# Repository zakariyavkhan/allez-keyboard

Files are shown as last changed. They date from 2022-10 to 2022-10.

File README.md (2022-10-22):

allez

An STM32F103 based 40% mechanical keyboard. PCB and switch plate designed in KiCAD.

- Custom firmware supported through QMK
    - [allez](https://github.com/zakariyavkhan/qmk_firmware/tree/master/keyboards/allez)
    - [allez-hw](https://github.com/zakariyavkhan/qmk_firmware/tree/master/keyboards/allez_hw)

PCBs and switch plates can be ordered through JLCPCB, who will also do PCBA for a very reasonable price. BOM will have to be generated via LCSC.

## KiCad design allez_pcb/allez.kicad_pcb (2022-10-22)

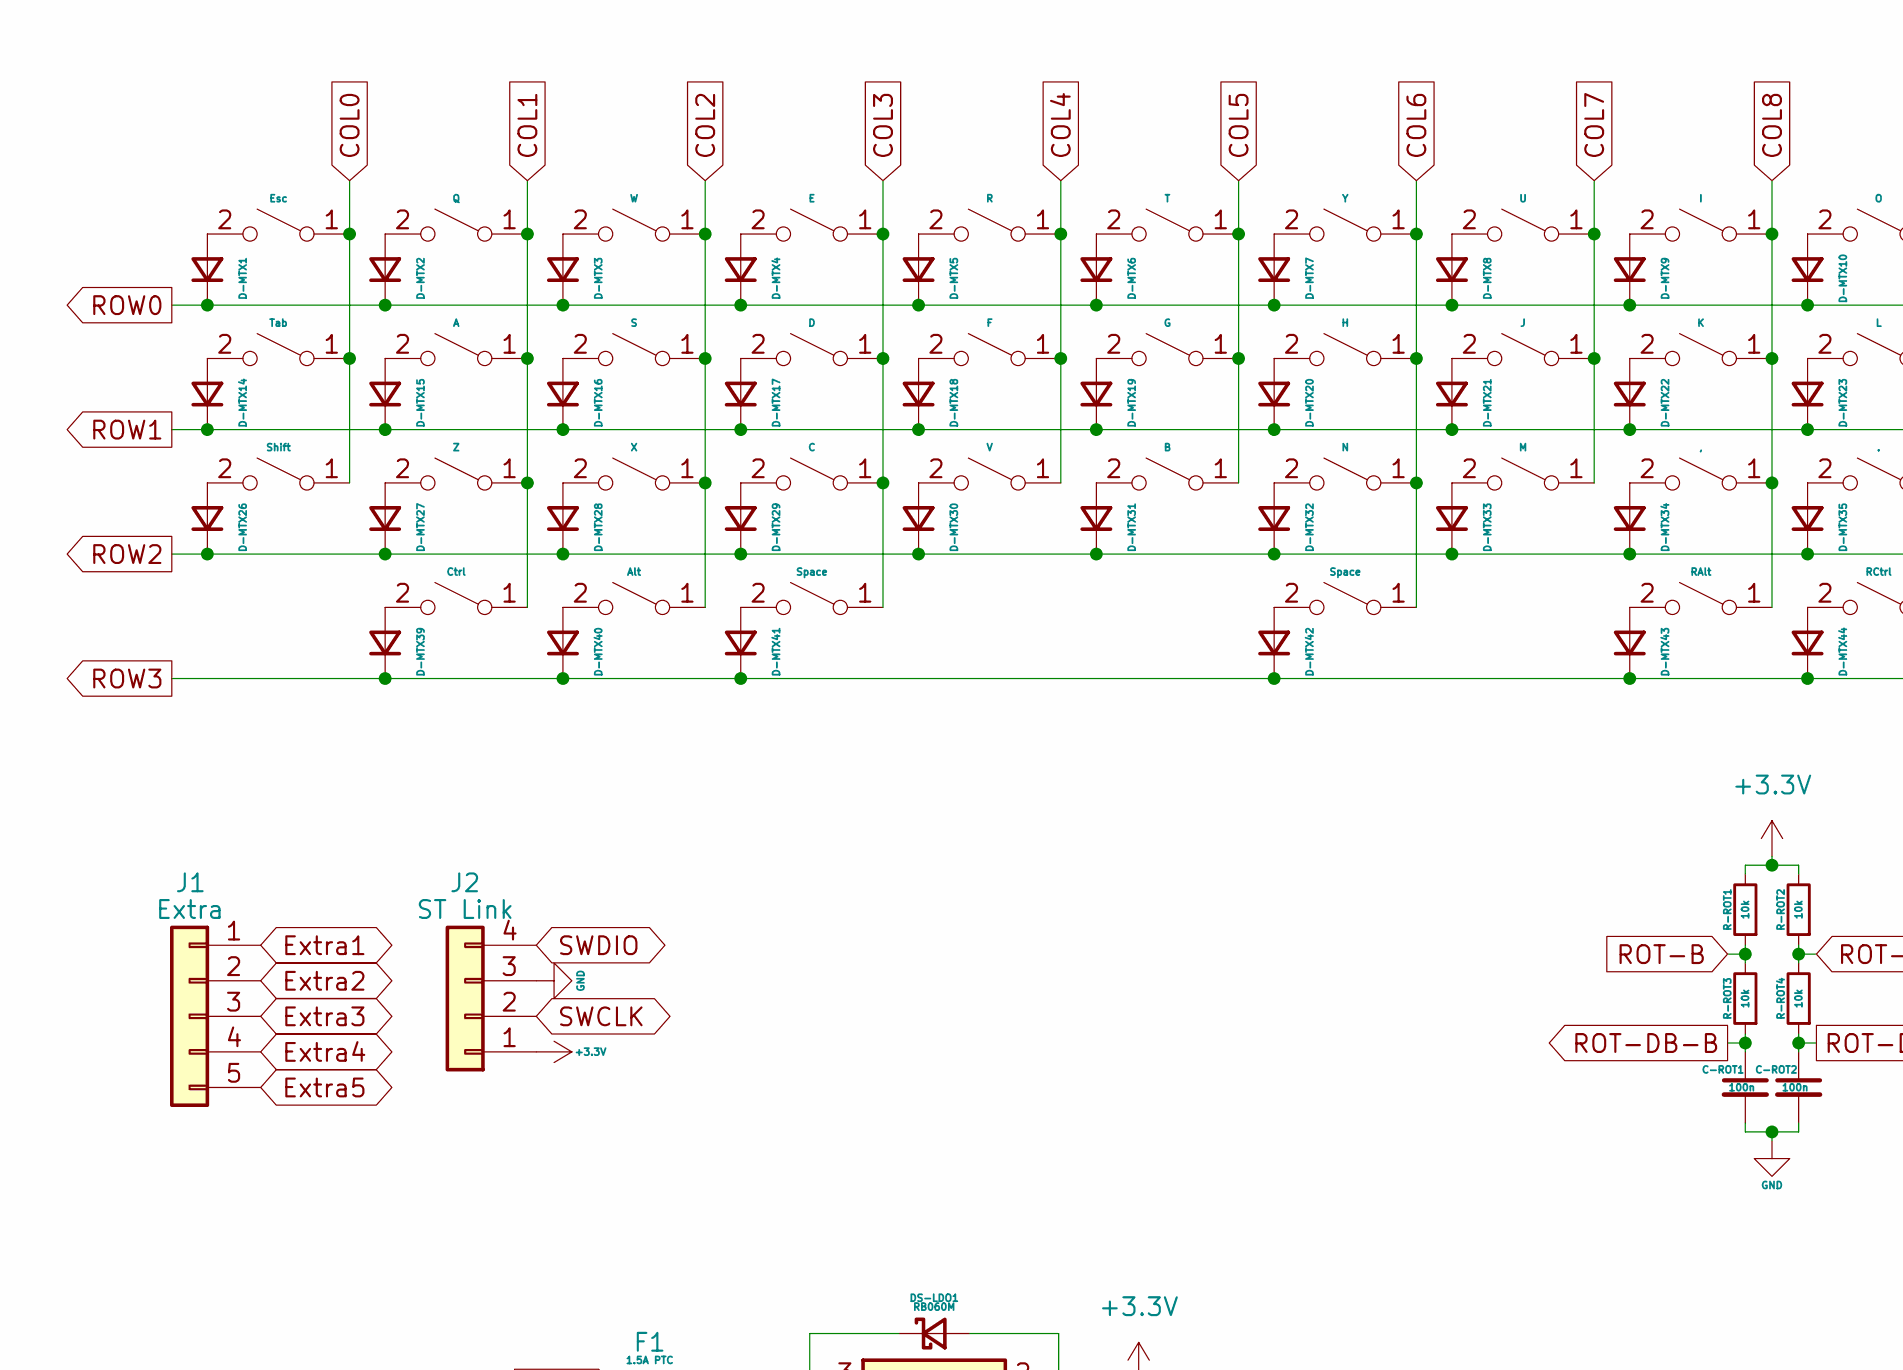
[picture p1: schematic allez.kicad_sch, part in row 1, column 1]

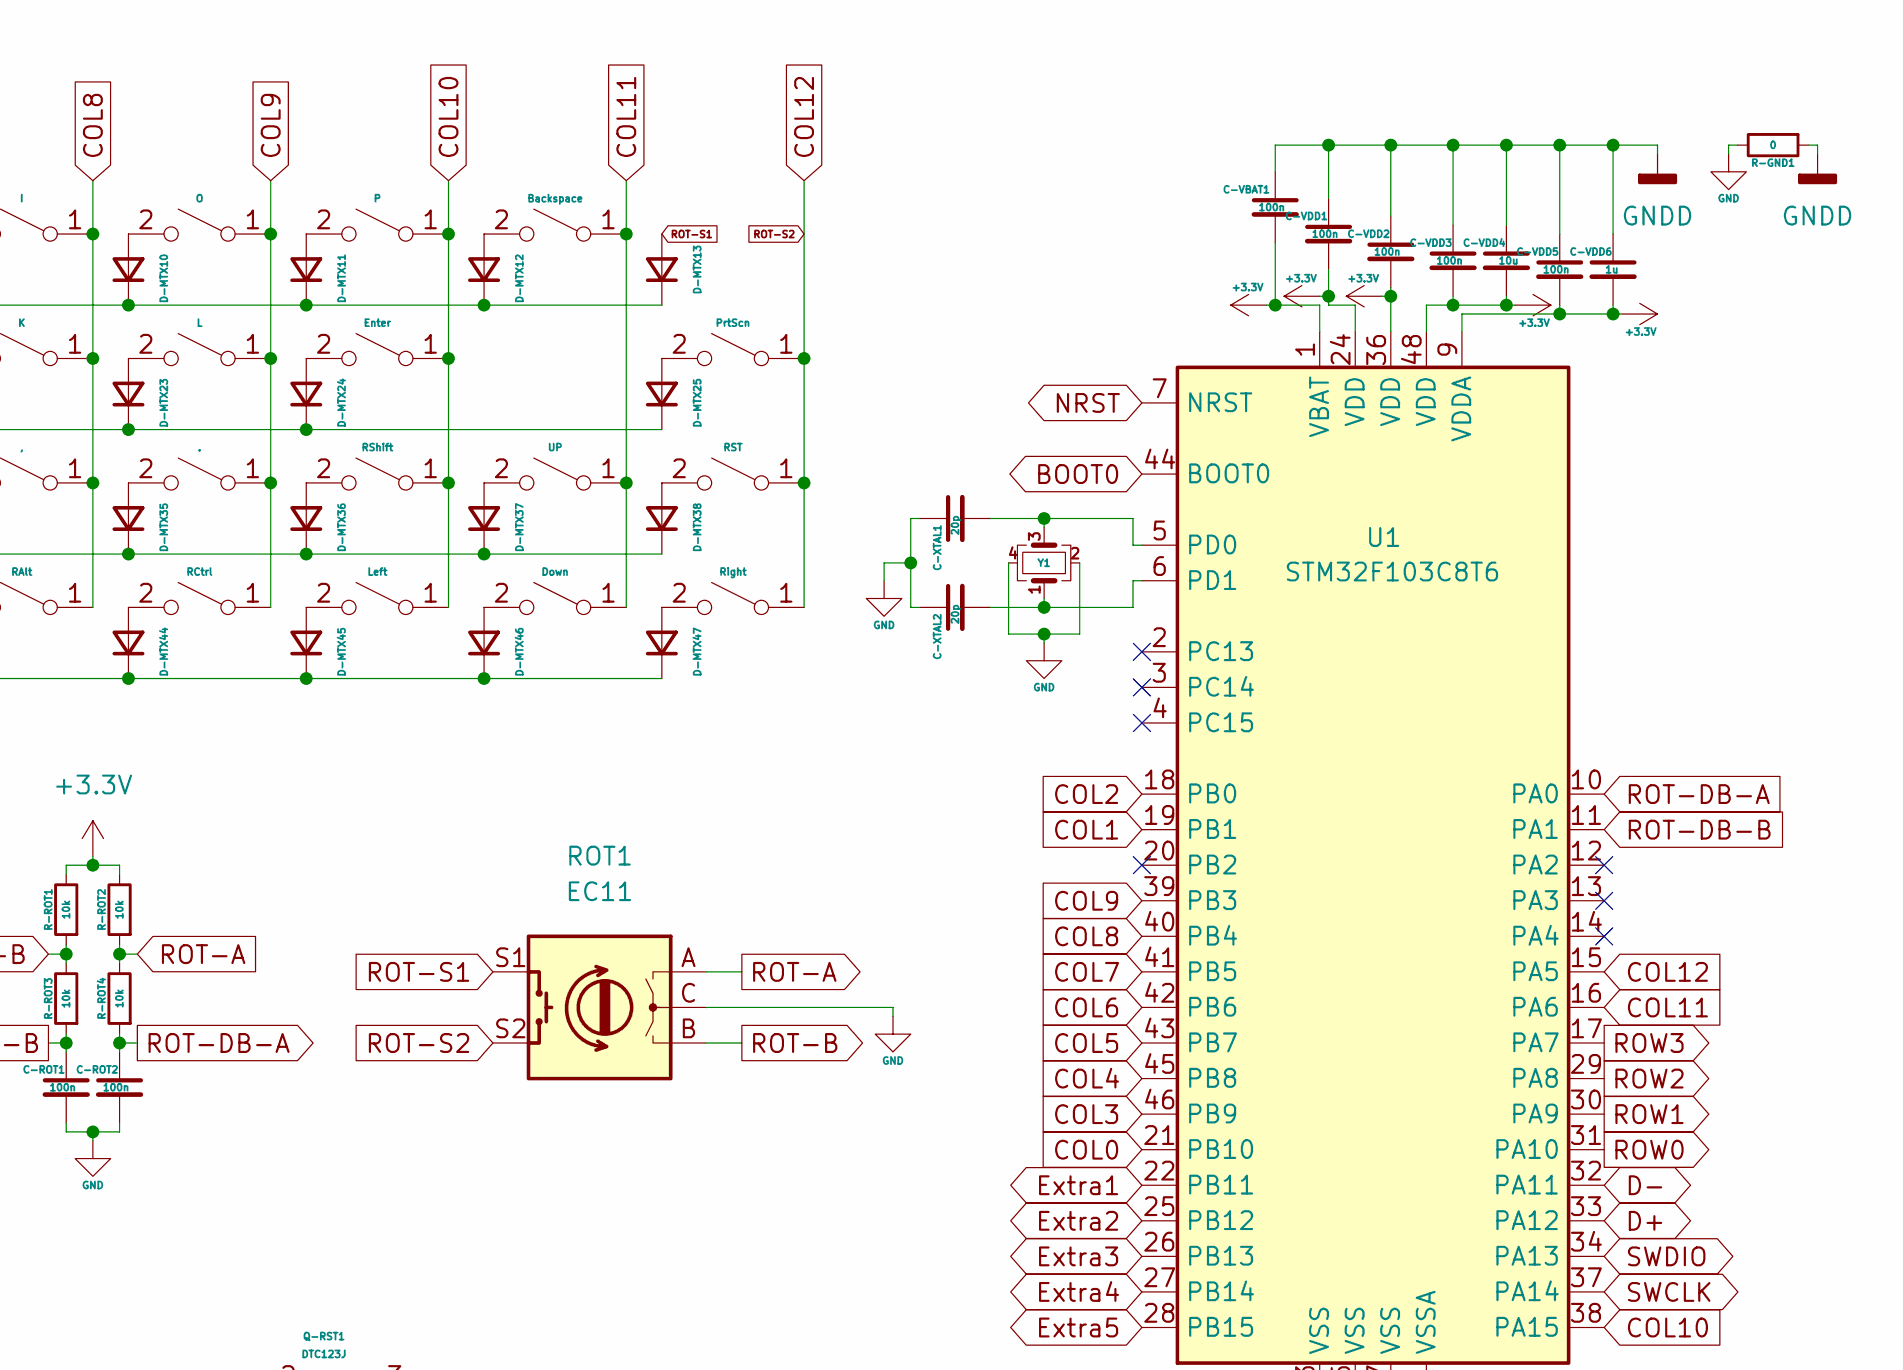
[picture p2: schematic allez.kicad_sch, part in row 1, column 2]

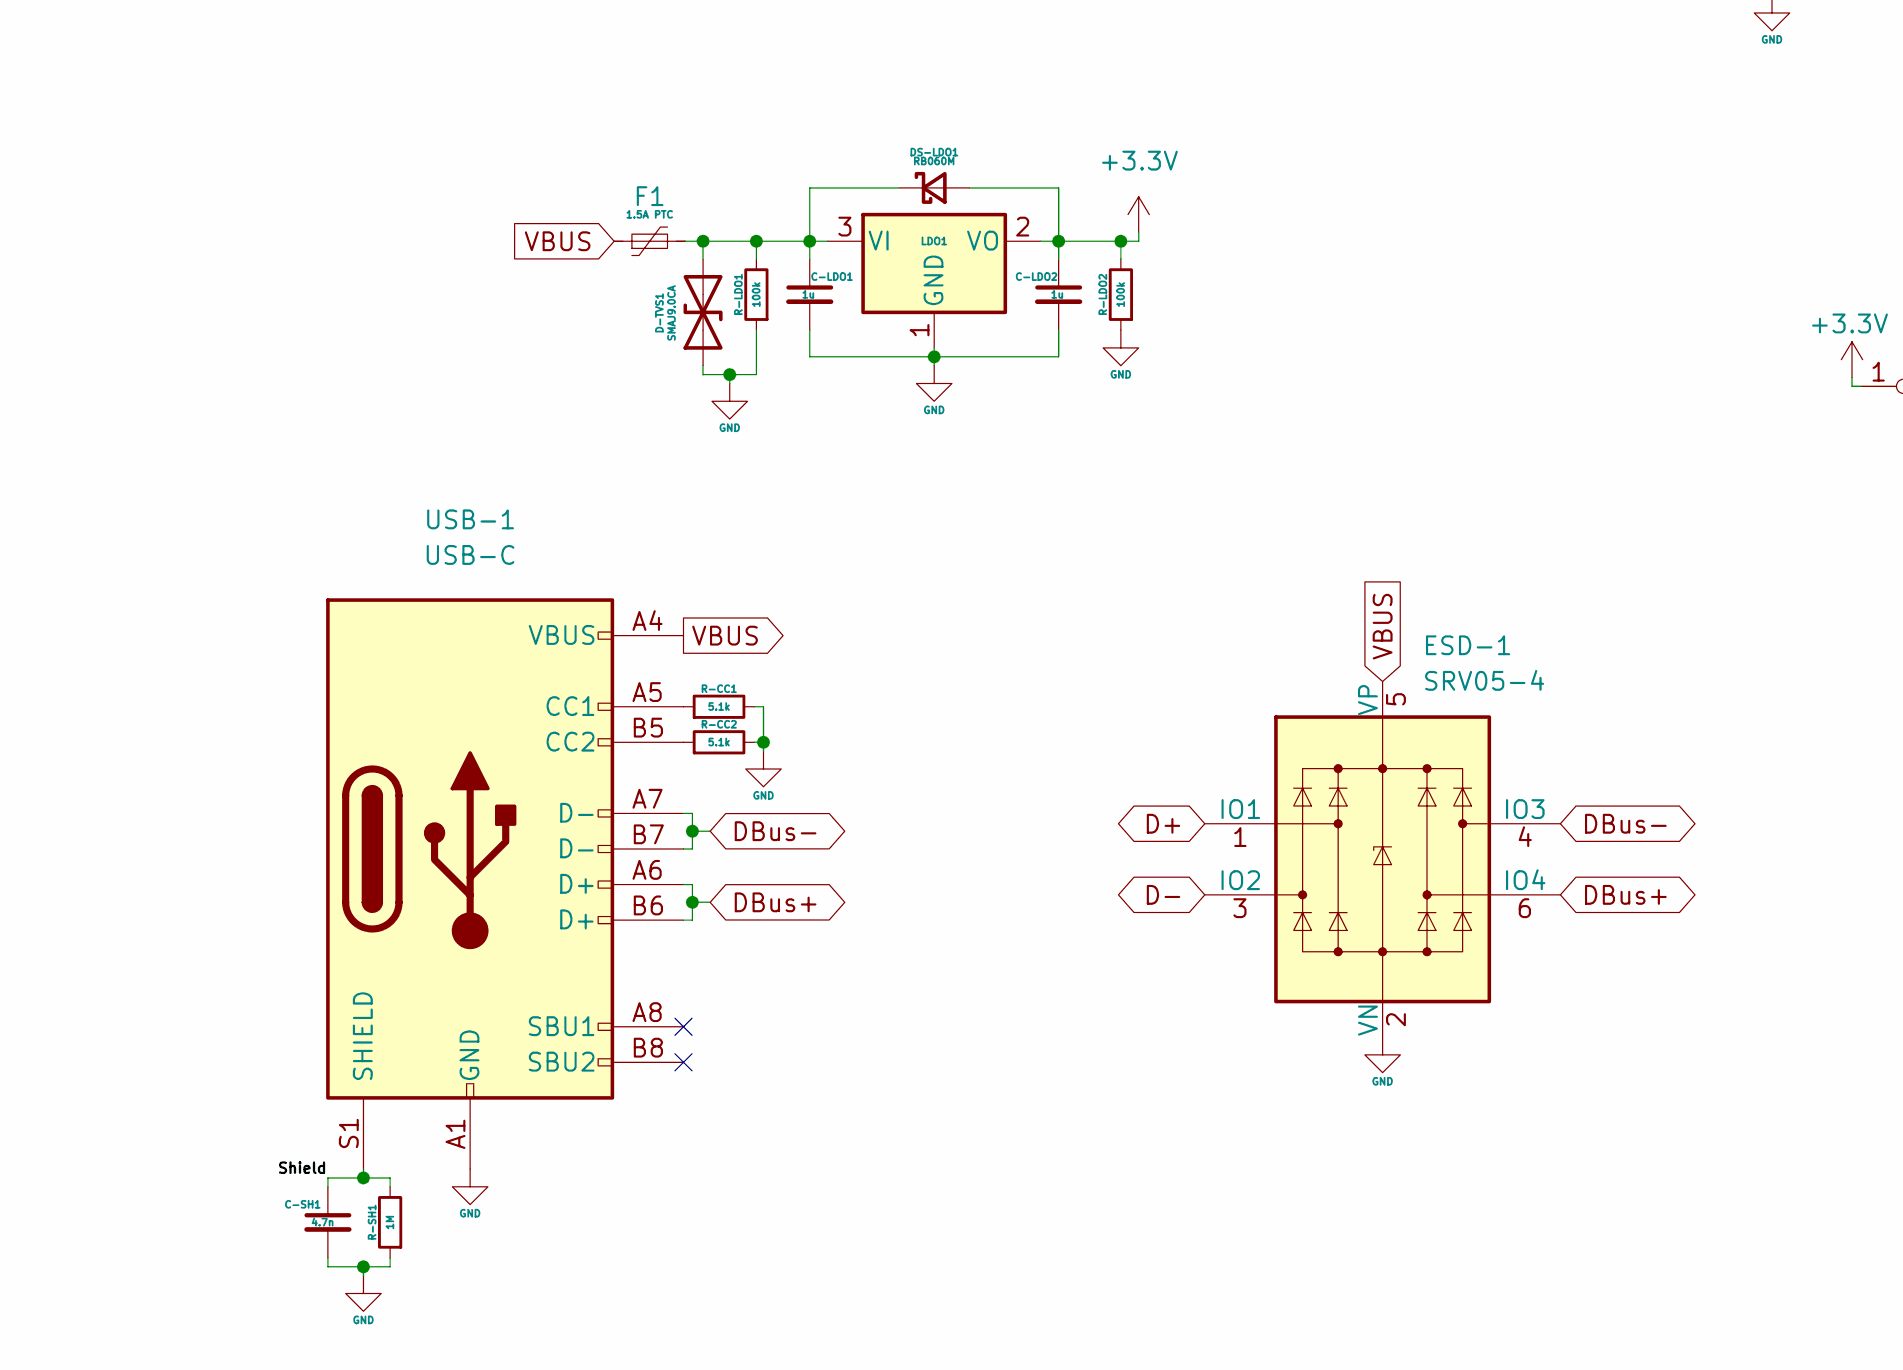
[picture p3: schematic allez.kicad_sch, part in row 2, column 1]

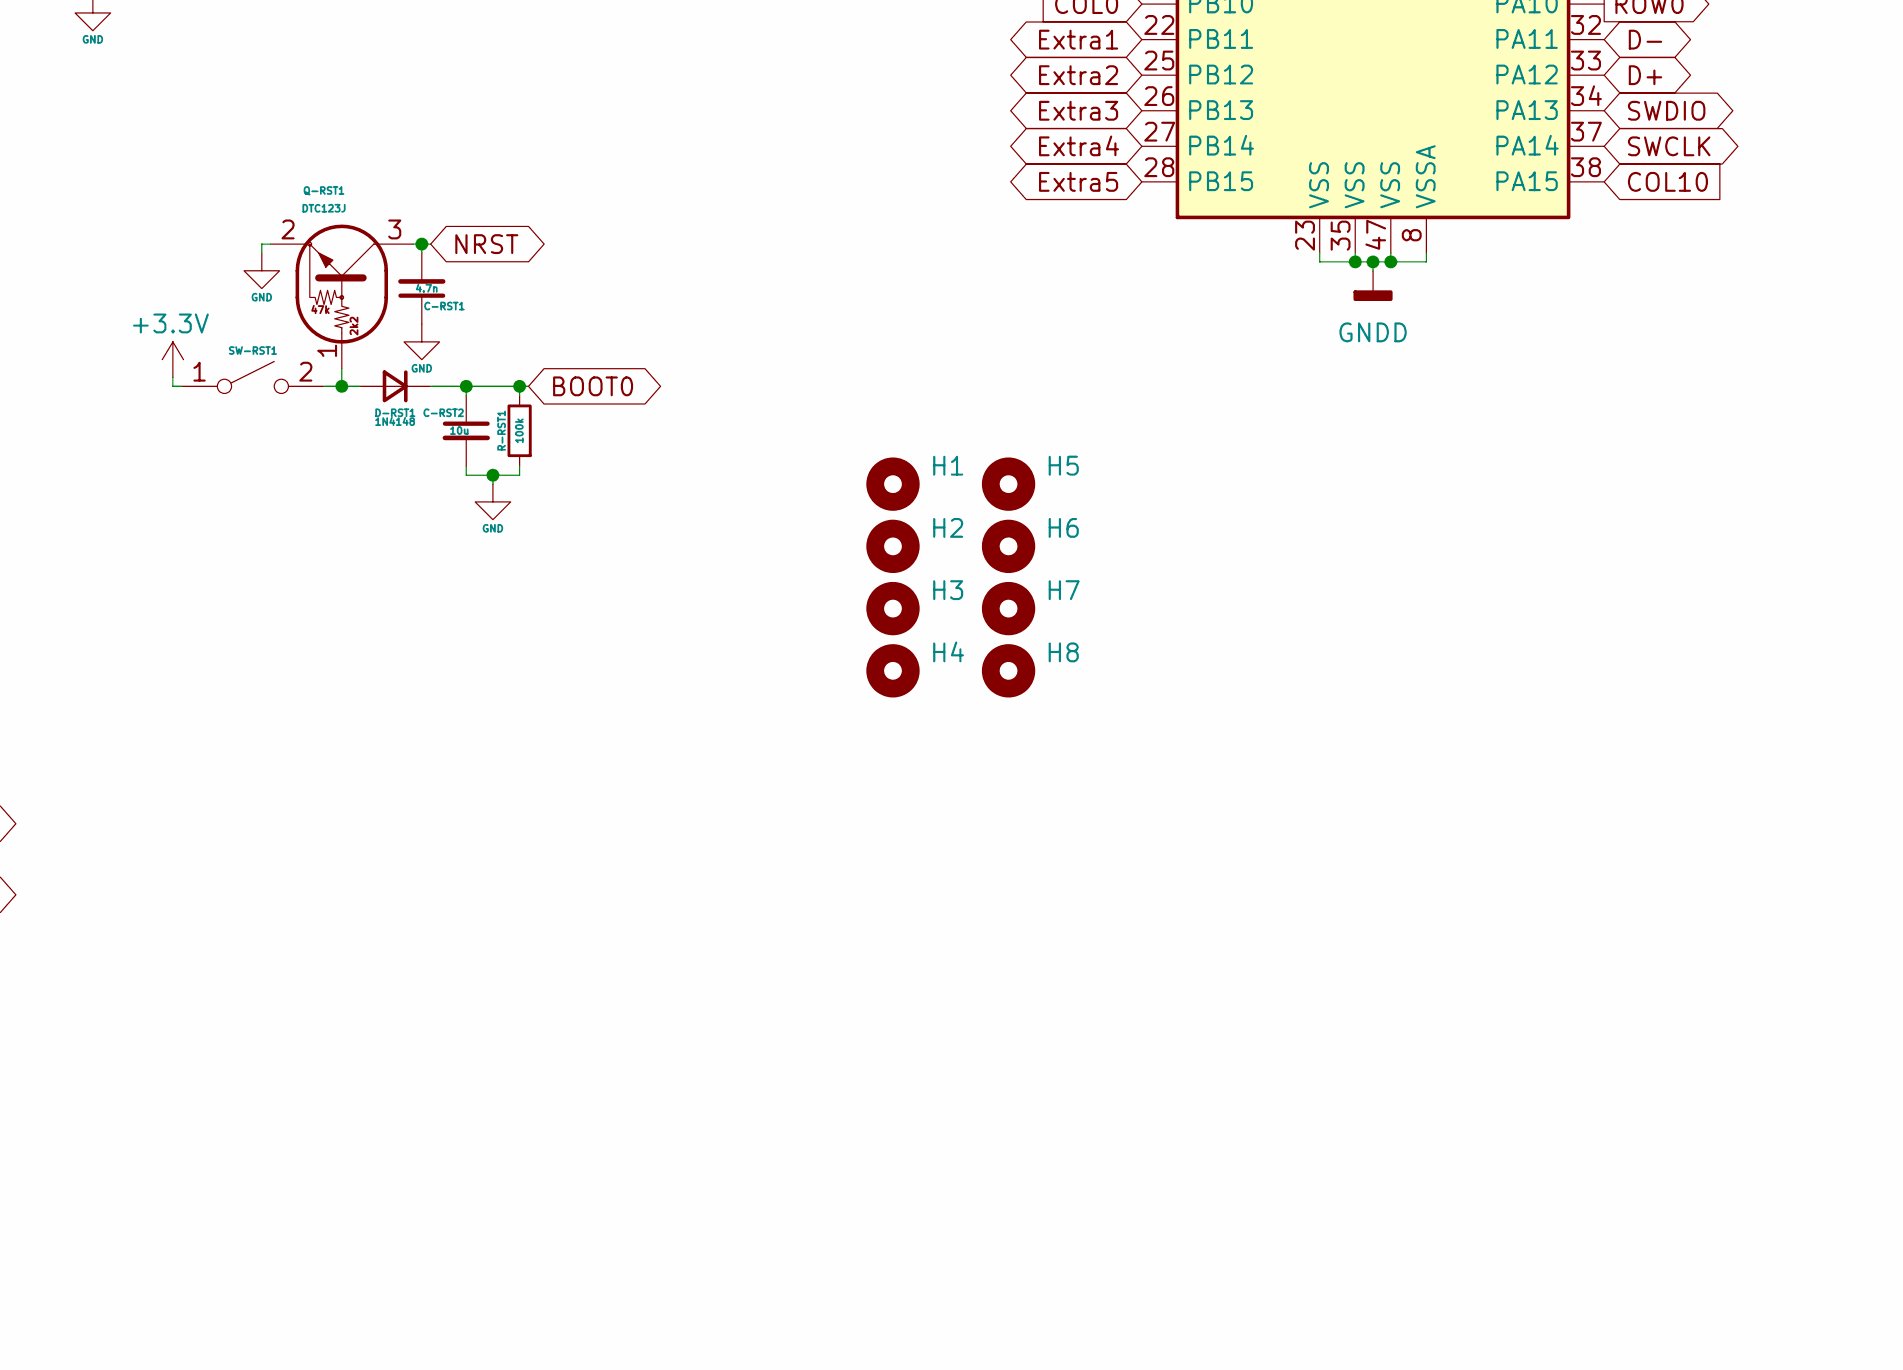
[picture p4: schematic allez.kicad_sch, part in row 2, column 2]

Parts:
C-LDO1, C-LDO2: 1u; C_0603_1608Metric_Pad1.08x0.95mm_HandSolder
C-ROT1, C-ROT2: 100n; C_0603_1608Metric_Pad1.08x0.95mm_HandSolder
C-RST1: 4.7n; C_0603_1608Metric_Pad1.08x0.95mm_HandSolder
C-RST2: 10u; C_0603_1608Metric_Pad1.08x0.95mm_HandSolder
C-SH1: 4.7n; C_0603_1608Metric_Pad1.08x0.95mm_HandSolder
C-VBAT1: 100n; C_0603_1608Metric_Pad1.08x0.95mm_HandSolder
C-VDD1, C-VDD2, C-VDD3, C-VDD5: 100n; C_0603_1608Metric_Pad1.08x0.95mm_HandSolder
C-VDD4: 10u; C_0603_1608Metric_Pad1.08x0.95mm_HandSolder
C-VDD6: 1u; C_0603_1608Metric_Pad1.08x0.95mm_HandSolder
C-XTAL1, C-XTAL2: 20p; C_0603_1608Metric_Pad1.08x0.95mm_HandSolder
D-MTX1, D-MTX2, D-MTX3, D-MTX4, D-MTX5, D-MTX6, D-MTX7, D-MTX8, D-MTX9, D-MTX10, D-MTX11, D-MTX12, D-MTX13, D-MTX14, D-MTX15, D-MTX16, D-MTX17, D-MTX18, D-MTX19, D-MTX20, D-MTX21, D-MTX22, D-MTX23, D-MTX24, D-MTX25, D-MTX26, D-MTX27, D-MTX28, D-MTX29, D-MTX30, D-MTX31, D-MTX32, D-MTX33, D-MTX34, D-MTX35, D-MTX36, D-MTX37, D-MTX38, D-MTX39, D-MTX40, D-MTX41, D-MTX42, D-MTX43, D-MTX44, D-MTX45, D-MTX46, D-MTX47: 1N4148; D_0603_1608Metric_Pad1.05x0.95mm_HandSolder
D-RST1: 1N4148; D_0603_1608Metric_Pad1.05x0.95mm_HandSolder
D-TVS1: SMAJ9.0CA; D_SMA
DS-LDO1: RB060M; D_SOD-123F
ESD-1: SRV05-4; SOT-23-6
F1: 1.5A PTC; Fuse_1812_4532Metric_Pad1.30x3.40mm_HandSolder
H1, H2, H3, H4, H5, H6, H7, H8: MountingHole; MountingHole_3.2mm_M3
J1: Extra; PinHeader_1x05_P2.54mm_Vertical
J2: ST Link; PinHeader_1x04_P2.54mm_Vertical
LDO1: XC6206; SOT-23
MX1: Esc; SW_Cherry_MX_1.00u_PCB
MX2: Q; SW_Cherry_MX_1.00u_PCB
MX3: W; SW_Cherry_MX_1.00u_PCB
MX4: E; SW_Cherry_MX_1.00u_PCB
MX5: R; SW_Cherry_MX_1.00u_PCB
MX6: T; SW_Cherry_MX_1.00u_PCB
MX7: Y; SW_Cherry_MX_1.00u_PCB
MX8: U; SW_Cherry_MX_1.00u_PCB
MX9: I; SW_Cherry_MX_1.00u_PCB
MX10: O; SW_Cherry_MX_1.00u_PCB
MX11: P; SW_Cherry_MX_1.00u_PCB
MX12: Backspace; SW_Cherry_MX_1.00u_PCB
MX14: Tab; SW_Cherry_MX_1.25u_PCB
MX15: A; SW_Cherry_MX_1.00u_PCB
MX16: S; SW_Cherry_MX_1.00u_PCB
MX17: D; SW_Cherry_MX_1.00u_PCB
MX18: F; SW_Cherry_MX_1.00u_PCB
MX19: G; SW_Cherry_MX_1.00u_PCB
MX20: H; SW_Cherry_MX_1.00u_PCB
MX21: J; SW_Cherry_MX_1.00u_PCB
MX22: K; SW_Cherry_MX_1.00u_PCB
MX23: L; SW_Cherry_MX_1.00u_PCB
MX24: Enter; SW_Cherry_MX_1.75u_PCB
MX25: PrtScn; SW_Cherry_MX_1.00u_PCB
MX26: Shift; SW_Cherry_MX_1.50u_PCB
MX27: Z; SW_Cherry_MX_1.00u_PCB
MX28: X; SW_Cherry_MX_1.00u_PCB
MX29: C; SW_Cherry_MX_1.00u_PCB
MX30: V; SW_Cherry_MX_1.00u_PCB
MX31: B; SW_Cherry_MX_1.00u_PCB
MX32: N; SW_Cherry_MX_1.00u_PCB
MX33: M; SW_Cherry_MX_1.00u_PCB
MX34: ,; SW_Cherry_MX_1.00u_PCB
MX35: .; SW_Cherry_MX_1.00u_PCB
MX36: RShift; SW_Cherry_MX_1.25u_PCB
MX37: UP; SW_Cherry_MX_1.00u_PCB
MX38: RST; SW_Cherry_MX_1.00u_PCB
MX39: Ctrl; SW_Cherry_MX_1.25u_PCB
MX40: Alt; SW_Cherry_MX_1.00u_PCB
MX41: Space; SW_Cherry_MX_2.25u_PCB
MX42: Space; SW_Cherry_MX_2.75u_PCB
MX43: RAlt; SW_Cherry_MX_1.00u_PCB
MX44: RCtrl; SW_Cherry_MX_1.25u_PCB
MX45: Left; SW_Cherry_MX_1.00u_PCB
MX46: Down; SW_Cherry_MX_1.00u_PCB
MX47: Right; SW_Cherry_MX_1.00u_PCB
Q-RST1: DTC123J; SOT-23
R-CC1, R-CC2: 5.1k; R_0603_1608Metric_Pad0.98x0.95mm_HandSolder
R-GND1: 0; R_0603_1608Metric_Pad0.98x0.95mm_HandSolder
R-LDO1, R-LDO2: 100k; R_0603_1608Metric_Pad0.98x0.95mm_HandSolder
R-ROT1, R-ROT2, R-ROT3, R-ROT4: 10k; R_0603_1608Metric_Pad0.98x0.95mm_HandSolder
R-RST1: 100k; R_0603_1608Metric_Pad0.98x0.95mm_HandSolder
R-SH1: 1M; R_0603_1608Metric_Pad0.98x0.95mm_HandSolder
ROT1: EC11; RotaryEncoder_Alps_EC11E-Switch_Vertical_H20mm
SW-RST1: SPST; SW_SPST_TL3342
U1: STM32F103C8T6; LQFP-48_7x7mm_P0.5mm
USB-1: USB-C; USB_C_Receptacle_HRO_TYPE-C-31-M-12
Y1: 8MHz; Crystal_SMD_3225-4Pin_3.2x2.5mm_HandSoldering

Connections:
+3.3V: C-LDO2.1, C-VBAT1.2, C-VDD1.2, C-VDD2.2, C-VDD3.2, C-VDD4.2, C-VDD5.2, C-VDD6.2, DS-LDO1.2 (A), J2.1, LDO1.2 (VO), R-LDO2.2, R-ROT1.2, R-ROT2.2, SW-RST1.1 (A), U1.1 (VBAT), U1.9 (VDDA), U1.24 (VDD), U1.36 (VDD), U1.48 (VDD)
/Shield: C-SH1.1, R-SH1.2, USB-1.S1 (SHIELD)
BOOT0: C-RST2.1, D-RST1.1 (K), R-RST1.2, U1.44 (BOOT0)
COL0: MX1.1 (A), MX14.1 (A), MX26.1 (A), U1.21 (PB10)
COL1: MX2.1 (A), MX15.1 (A), MX27.1 (A), MX39.1 (A), U1.19 (PB1)
COL2: MX3.1 (A), MX16.1 (A), MX28.1 (A), MX40.1 (A), U1.18 (PB0)
COL3: MX4.1 (A), MX17.1 (A), MX29.1 (A), MX41.1 (A), U1.46 (PB9)
COL4: MX5.1 (A), MX18.1 (A), MX30.1 (A), U1.45 (PB8)
COL5: MX6.1 (A), MX19.1 (A), MX31.1 (A), U1.43 (PB7)
COL6: MX7.1 (A), MX20.1 (A), MX32.1 (A), MX42.1 (A), U1.42 (PB6)
COL7: MX8.1 (A), MX21.1 (A), MX33.1 (A), U1.41 (PB5)
COL8: MX9.1 (A), MX22.1 (A), MX34.1 (A), MX43.1 (A), U1.40 (PB4)
COL9: MX10.1 (A), MX23.1 (A), MX35.1 (A), MX44.1 (A), U1.39 (PB3)
COL10: MX11.1 (A), MX24.1 (A), MX36.1 (A), MX45.1 (A), U1.38 (PA15)
COL11: MX12.1 (A), MX37.1 (A), MX46.1 (A), U1.16 (PA6)
COL12: MX25.1 (A), MX38.1 (A), MX47.1 (A), ROT1.S2, U1.15 (PA5)
D+: ESD-1.1 (IO1), U1.33 (PA12)
D-: ESD-1.3 (IO2), U1.32 (PA11)
DBus+: ESD-1.6 (IO4), USB-1.A6 (D+), USB-1.B6 (D+)
DBus-: ESD-1.4 (IO3), USB-1.A7 (D-), USB-1.B7 (D-)
Extra1: J1.1, U1.22 (PB11)
Extra2: J1.2, U1.25 (PB12)
Extra3: J1.3, U1.26 (PB13)
Extra4: J1.4, U1.27 (PB14)
Extra5: J1.5, U1.28 (PB15)
GND: C-LDO1.2, C-LDO2.2, C-ROT1.2, C-ROT2.2, C-RST1.1, C-RST2.2, C-SH1.2, C-XTAL1.1, C-XTAL2.1, D-TVS1.1 (A1), ESD-1.2 (VN), J2.3, LDO1.1 (GND), Q-RST1.2 (E), R-CC1.2, R-CC2.2, R-GND1.2, R-LDO1.1, R-LDO2.1, R-RST1.1, R-SH1.1, ROT1.C, USB-1.A1 (GND), USB-1.A12 (GND), USB-1.B1 (GND), USB-1.B12 (GND), Y1.2, Y1.4
GNDD: C-VBAT1.1, C-VDD1.1, C-VDD2.1, C-VDD3.1, C-VDD4.1, C-VDD5.1, C-VDD6.1, R-GND1.1, U1.8 (VSSA), U1.23 (VSS), U1.35 (VSS), U1.47 (VSS)
NRST: C-RST1.2, Q-RST1.3 (C), U1.7 (NRST)
unnamed: C-LDO1.1, D-TVS1.2 (A2), DS-LDO1.1 (K), F1.2, LDO1.3 (VI), R-LDO1.2
unnamed: C-XTAL1.2, U1.5 (PD0), Y1.3
unnamed: C-XTAL2.2, U1.6 (PD1), Y1.1
unnamed: D-MTX1.2 (A), MX1.2 (B)
unnamed: D-MTX2.2 (A), MX2.2 (B)
unnamed: D-MTX3.2 (A), MX3.2 (B)
unnamed: D-MTX4.2 (A), MX4.2 (B)
unnamed: D-MTX5.2 (A), MX5.2 (B)
unnamed: D-MTX6.2 (A), MX6.2 (B)
unnamed: D-MTX7.2 (A), MX7.2 (B)
unnamed: D-MTX8.2 (A), MX8.2 (B)
unnamed: D-MTX9.2 (A), MX9.2 (B)
unnamed: D-MTX10.2 (A), MX10.2 (B)
unnamed: D-MTX11.2 (A), MX11.2 (B)
unnamed: D-MTX12.2 (A), MX12.2 (B)
unnamed: D-MTX14.2 (A), MX14.2 (B)
unnamed: D-MTX15.2 (A), MX15.2 (B)
unnamed: D-MTX16.2 (A), MX16.2 (B)
unnamed: D-MTX17.2 (A), MX17.2 (B)
unnamed: D-MTX18.2 (A), MX18.2 (B)
unnamed: D-MTX19.2 (A), MX19.2 (B)
unnamed: D-MTX20.2 (A), MX20.2 (B)
unnamed: D-MTX21.2 (A), MX21.2 (B)
unnamed: D-MTX22.2 (A), MX22.2 (B)
unnamed: D-MTX23.2 (A), MX23.2 (B)
unnamed: D-MTX24.2 (A), MX24.2 (B)
unnamed: D-MTX25.2 (A), MX25.2 (B)
unnamed: D-MTX26.2 (A), MX26.2 (B)
unnamed: D-MTX27.2 (A), MX27.2 (B)
unnamed: D-MTX28.2 (A), MX28.2 (B)
unnamed: D-MTX29.2 (A), MX29.2 (B)
unnamed: D-MTX30.2 (A), MX30.2 (B)
unnamed: D-MTX31.2 (A), MX31.2 (B)
unnamed: D-MTX32.2 (A), MX32.2 (B)
unnamed: D-MTX33.2 (A), MX33.2 (B)
unnamed: D-MTX34.2 (A), MX34.2 (B)
unnamed: D-MTX35.2 (A), MX35.2 (B)
unnamed: D-MTX36.2 (A), MX36.2 (B)
unnamed: D-MTX37.2 (A), MX37.2 (B)
unnamed: D-MTX38.2 (A), MX38.2 (B)
unnamed: D-MTX39.2 (A), MX39.2 (B)
unnamed: D-MTX40.2 (A), MX40.2 (B)
unnamed: D-MTX41.2 (A), MX41.2 (B)
unnamed: D-MTX42.2 (A), MX42.2 (B)
unnamed: D-MTX43.2 (A), MX43.2 (B)
unnamed: D-MTX44.2 (A), MX44.2 (B)
unnamed: D-MTX45.2 (A), MX45.2 (B)
unnamed: D-MTX46.2 (A), MX46.2 (B)
unnamed: D-MTX47.2 (A), MX47.2 (B)
unnamed: D-RST1.2 (A), Q-RST1.1 (B), SW-RST1.2 (B)
unnamed: R-CC1.1, USB-1.A5 (CC1)
unnamed: R-CC2.1, USB-1.B5 (CC2)
ROT-A: R-ROT2.1, R-ROT4.2, ROT1.A
ROT-B: R-ROT1.1, R-ROT3.2, ROT1.B
ROT-DB-A: C-ROT2.1, R-ROT4.1, U1.10 (PA0)
ROT-DB-B: C-ROT1.1, R-ROT3.1, U1.11 (PA1)
ROT-S1: D-MTX13.2 (A), ROT1.S1
ROW0: D-MTX1.1 (K), D-MTX2.1 (K), D-MTX3.1 (K), D-MTX4.1 (K), D-MTX5.1 (K), D-MTX6.1 (K), D-MTX7.1 (K), D-MTX8.1 (K), D-MTX9.1 (K), D-MTX10.1 (K), D-MTX11.1 (K), D-MTX12.1 (K), D-MTX13.1 (K), U1.31 (PA10)
ROW1: D-MTX14.1 (K), D-MTX15.1 (K), D-MTX16.1 (K), D-MTX17.1 (K), D-MTX18.1 (K), D-MTX19.1 (K), D-MTX20.1 (K), D-MTX21.1 (K), D-MTX22.1 (K), D-MTX23.1 (K), D-MTX24.1 (K), D-MTX25.1 (K), U1.30 (PA9)
ROW2: D-MTX26.1 (K), D-MTX27.1 (K), D-MTX28.1 (K), D-MTX29.1 (K), D-MTX30.1 (K), D-MTX31.1 (K), D-MTX32.1 (K), D-MTX33.1 (K), D-MTX34.1 (K), D-MTX35.1 (K), D-MTX36.1 (K), D-MTX37.1 (K), D-MTX38.1 (K), U1.29 (PA8)
ROW3: D-MTX39.1 (K), D-MTX40.1 (K), D-MTX41.1 (K), D-MTX42.1 (K), D-MTX43.1 (K), D-MTX44.1 (K), D-MTX45.1 (K), D-MTX46.1 (K), D-MTX47.1 (K), U1.17 (PA7)
SWCLK: J2.2, U1.37 (PA14)
SWDIO: J2.4, U1.34 (PA13)
VBUS: ESD-1.5 (VP), F1.1, USB-1.A4 (VBUS), USB-1.A9 (VBUS), USB-1.B4 (VBUS), USB-1.B9 (VBUS)

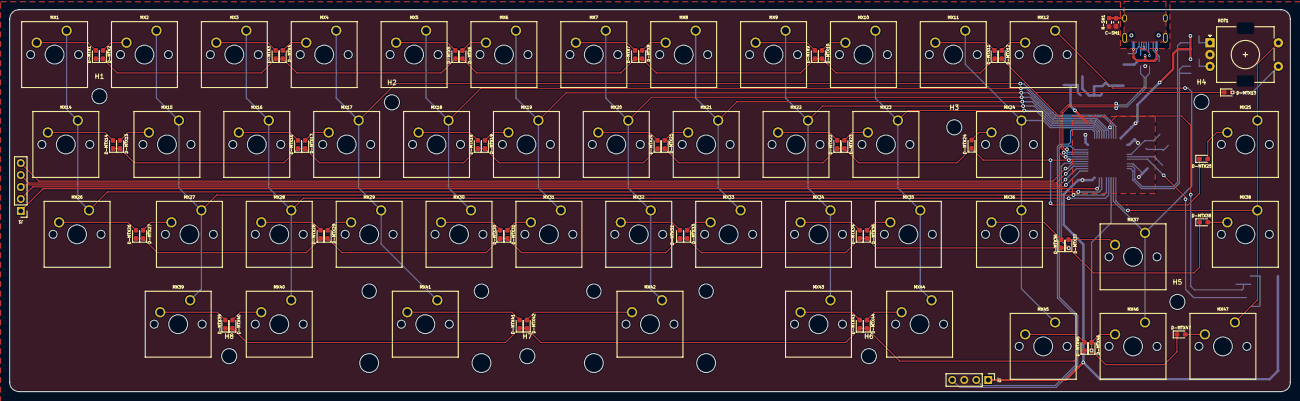
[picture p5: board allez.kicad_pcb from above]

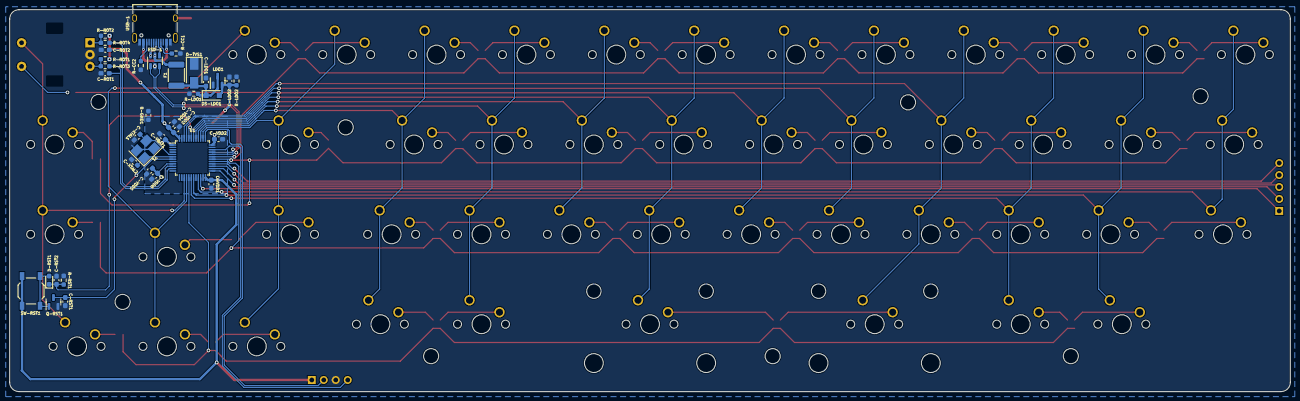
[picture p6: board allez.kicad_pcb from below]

Board: 2 copper layers, 271.5 x 81.0 mm, 142 parts (36 on the bottom side), 92 nets.
